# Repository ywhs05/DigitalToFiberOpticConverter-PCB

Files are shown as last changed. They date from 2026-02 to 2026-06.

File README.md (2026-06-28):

# DigitalToFiberOpticConverter-PCB

### Descripción
Proyecto del laboratorio LabCES de la Universidad de Costa Rica.

<!-- Este circuito tiene como objetivo recibir las señales digitales enviadas por medio de un microcontrolador para luego convertirlas en fibra óptica para que pueda ser leída por los puentes H [PEH2015 de Imperix](DaFO-PCB/Datasheets/PEH2015-PuenteH.pdf) en su entrada de fibra óptica. -->

Este circuito tiene como objetivo recibir una señal PWM digital enviada por medio de un microcontrolador, para luego ser convertida en una señal de fibra óptica para poder ser leída por los puentes H [PEH2015 de Imperix](DaFO-PCB/Datasheets/PEH2015-PuenteH.pdf) en su entrada de fibra óptica.

<!--![PCB](DAFO-PCB/Imagenes/PCB.png)-->

Ahora bien, la placa cuenta con la posiblidad de agregar o no, tiempo muerto a la señal PWM por seguridad de los transistores del puente H. Dicho tiempo muerto es ajustable mediante un trimmer. Por otra parte, es posible negar la señal PWM o no.

En adición, se puede adicionar una placa igual por encima de otra para aprovechar la señal PWM recibida del microcontrolador y se cuentan 3 huecos para colocar los pilares de nylon para su soporte.

Finalmente, se muestran las vistas superior e inferior de la PCB.

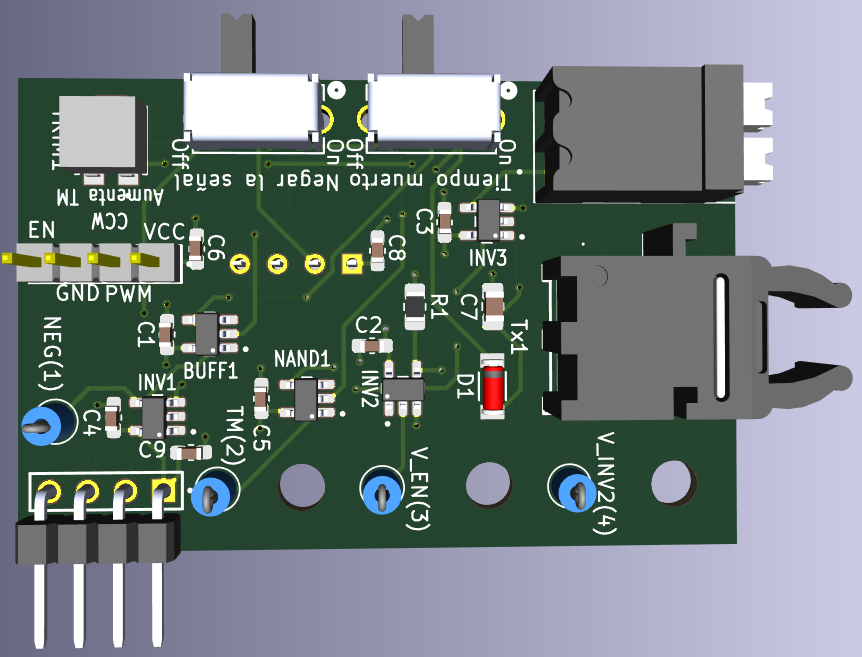
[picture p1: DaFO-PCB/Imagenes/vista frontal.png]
PCB_3D_sup


PCB_3D_inf

### Soporte
- y.huang@ucr.ac.cr
- mauricio.espinoza_bola@ucr.ac.cr

### Estado del proyecto

Se encuentra en proceso de pruebas experimentales.

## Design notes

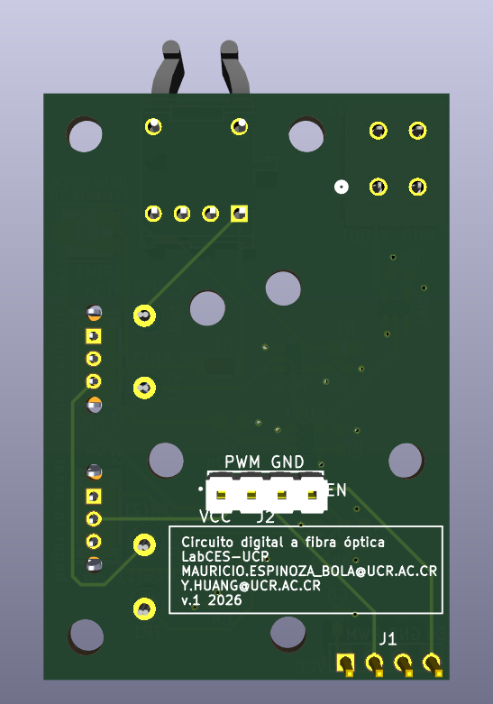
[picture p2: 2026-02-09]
DaFO-PCB/Imagenes/PCB_3D_inf.png

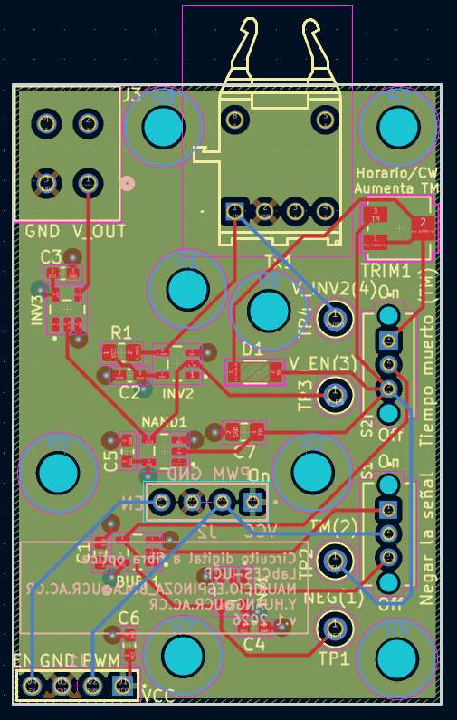
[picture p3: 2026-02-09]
DaFO-PCB/Imagenes/PCB.png

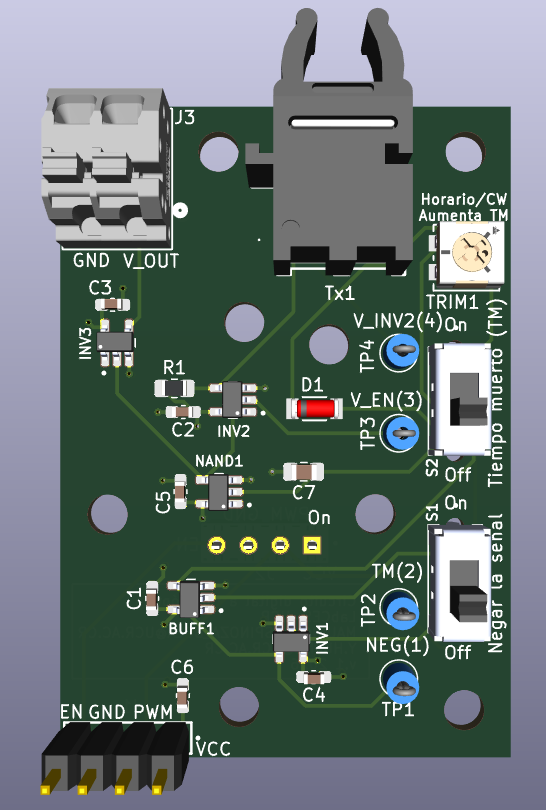
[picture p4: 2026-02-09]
DaFO-PCB/Imagenes/PCB_3D_sup.png

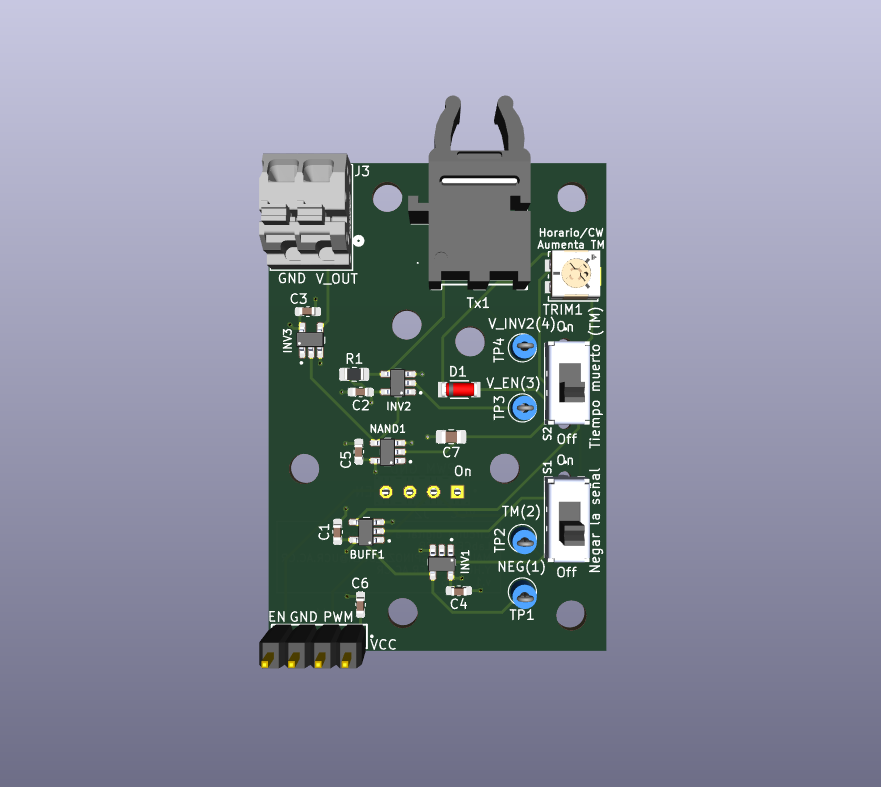
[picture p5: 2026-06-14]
DaFO-PCB/Imagenes/PCB_3D.png

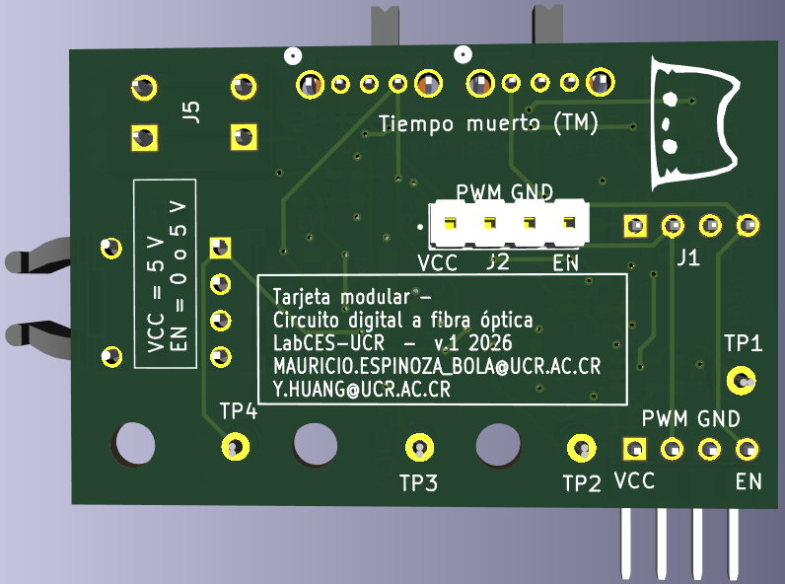
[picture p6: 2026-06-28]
DaFO-PCB/Imagenes/vista trasera.png

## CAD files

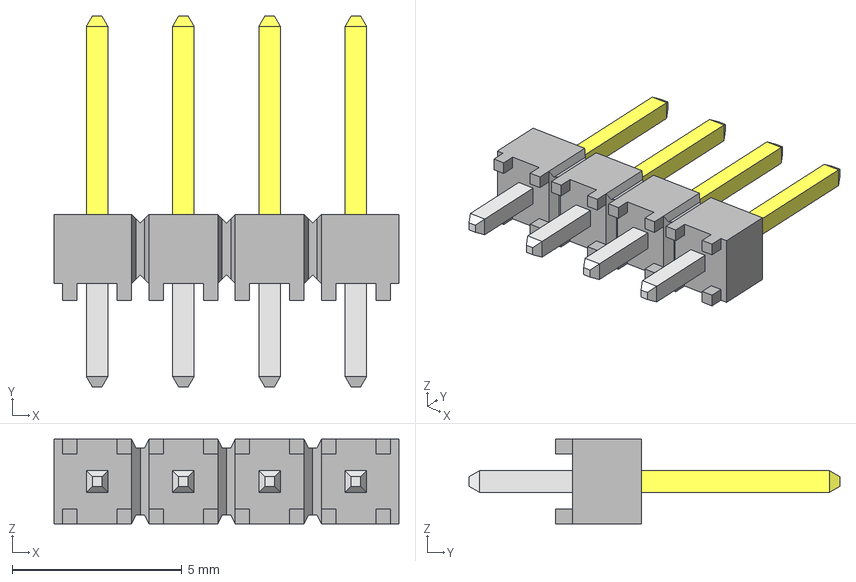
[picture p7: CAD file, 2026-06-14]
DaFO-PCB/DaFO/3D models/HTSW-104-07-F-S_3D.stp
10.2 x 10.9 x 2.49 mm
HTSW-104-07-F-S_body
T-1S6-07-HTSW-1--07-4--F-S
T-1S6-07-HTSW-1--07-4--F-S2

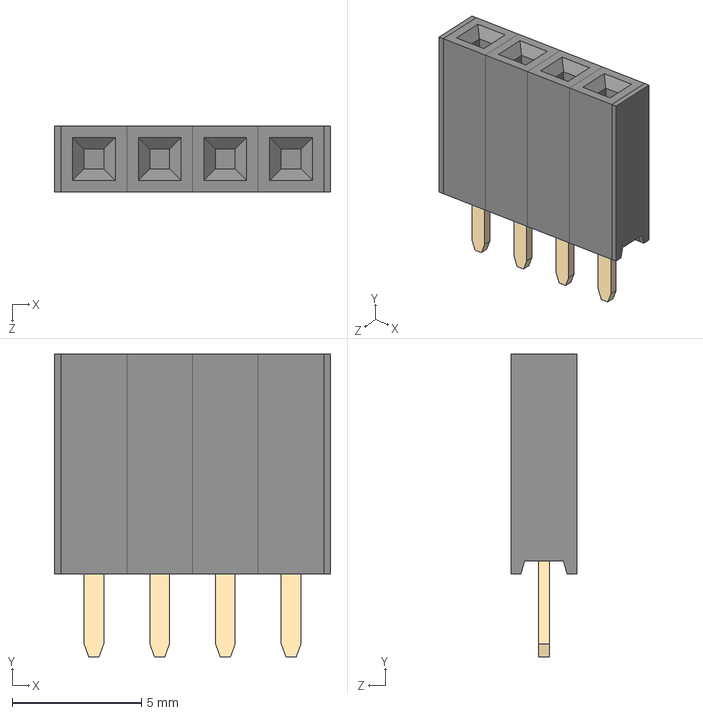
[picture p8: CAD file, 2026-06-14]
DaFO-PCB/DaFO/3D models/CONN_PPPC041LFBN-RC.STEP
10.7 x 11.7 x 2.54 mm
PPPC021LFBN-RC_C04
Pin - Gold x 4

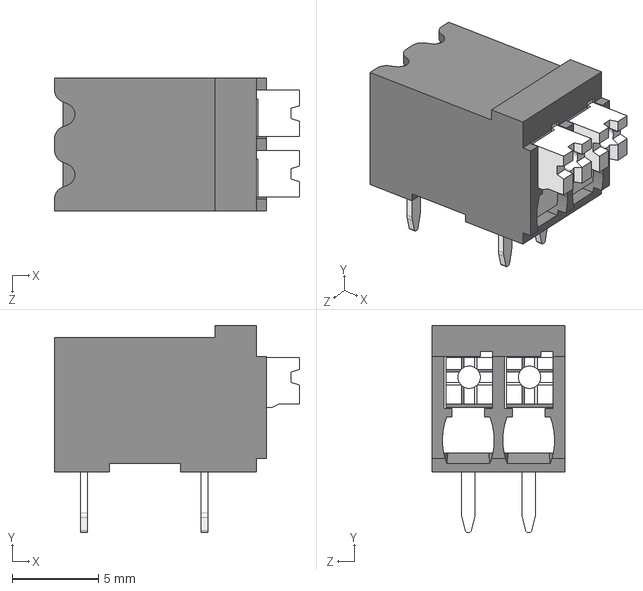
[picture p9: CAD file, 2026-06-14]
DaFO-PCB/DaFO/3D models/CON_TBLH10-350-02BK.step
14.2 x 12.0 x 7.70 mm

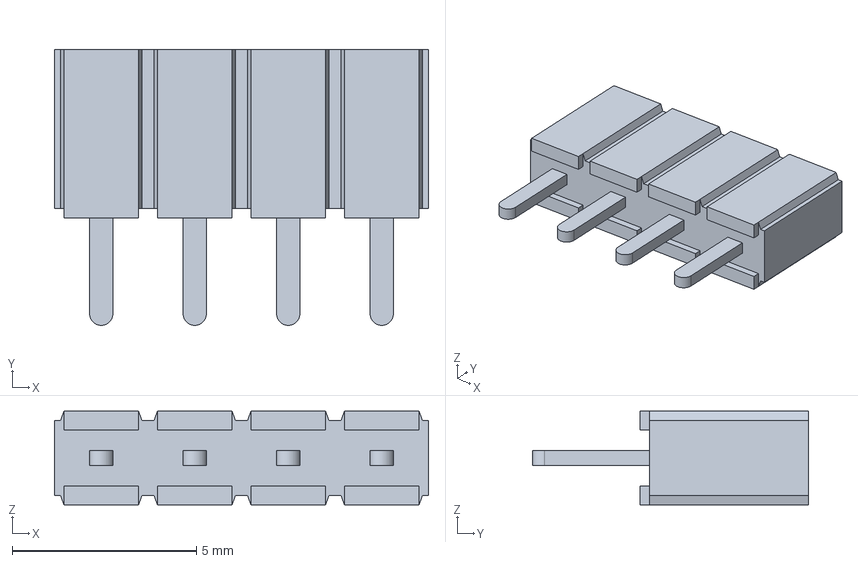
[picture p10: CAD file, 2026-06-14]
DaFO-PCB/DaFO/3D models/CONN_slw-104-01-f-s.stp
10.2 x 7.49 x 2.54 mm

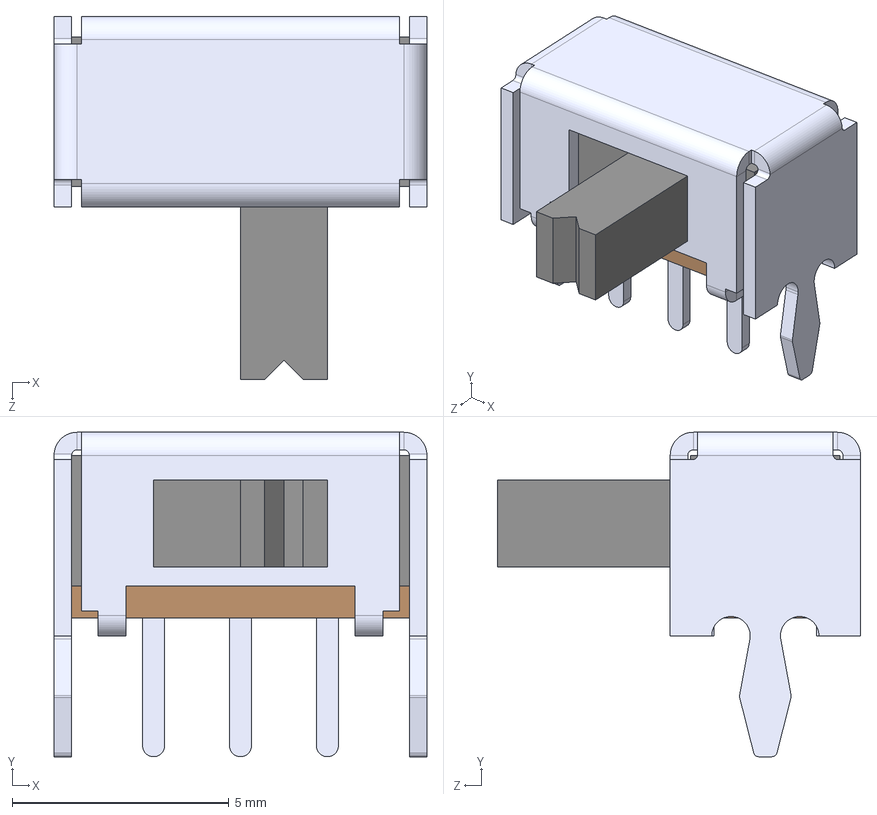
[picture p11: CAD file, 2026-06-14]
DaFO-PCB/DaFO/3D models/SWITCH_OS102011MA1QN1.STEP
8.61 x 7.49 x 8.38 mm

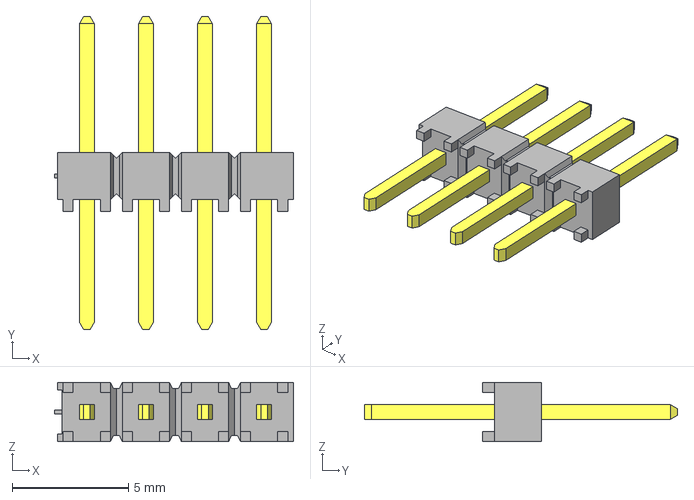
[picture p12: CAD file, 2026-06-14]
DaFO-PCB/DaFO/3D models/TSW-104-08-S-S.stp
10.3 x 13.5 x 2.54 mm
TSW-104-08-S-S_body
T-1S6-08-TSW-1-08-4-S

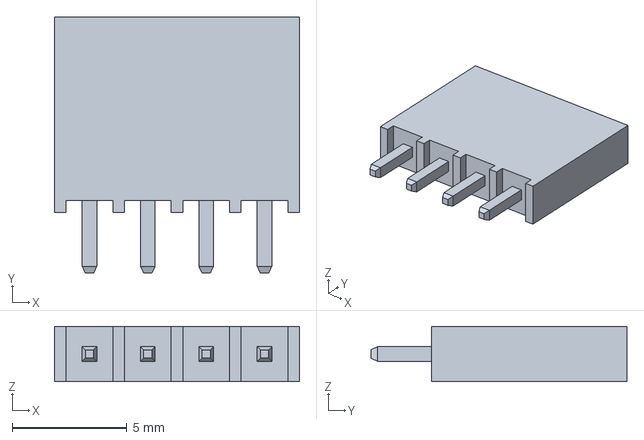
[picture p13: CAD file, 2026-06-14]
DaFO-PCB/DaFO/3D models/CONN_ssq-104-01-t-s.stp
10.7 x 11.2 x 2.41 mm

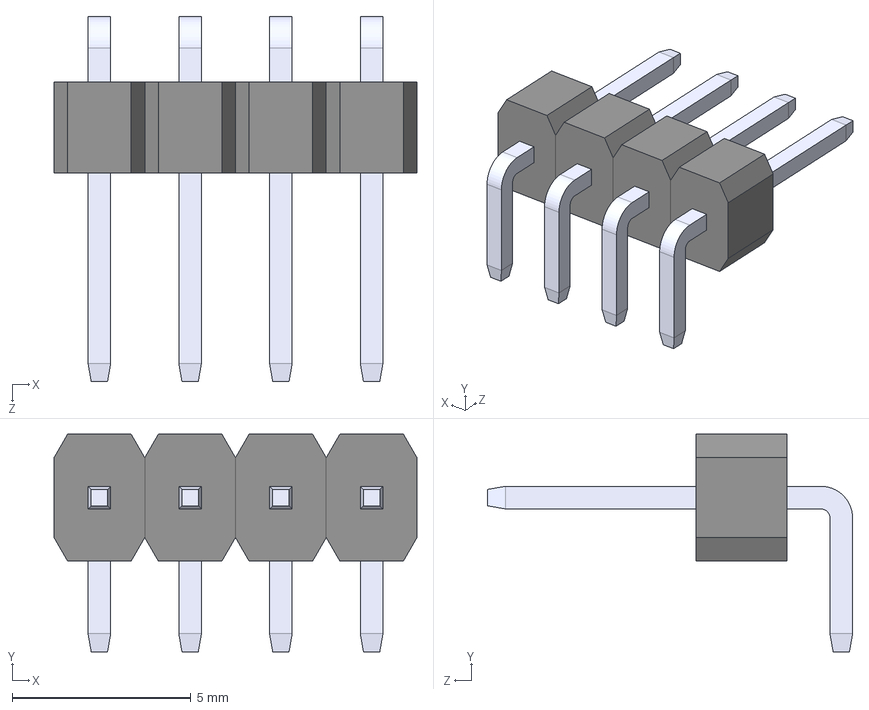
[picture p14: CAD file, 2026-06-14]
DaFO-PCB/DaFO/3D models/PEC04SBAN.STEP
10.2 x 6.10 x 10.2 mm
PBC04SBAN_GC04
Pin - Tin_BA x 4

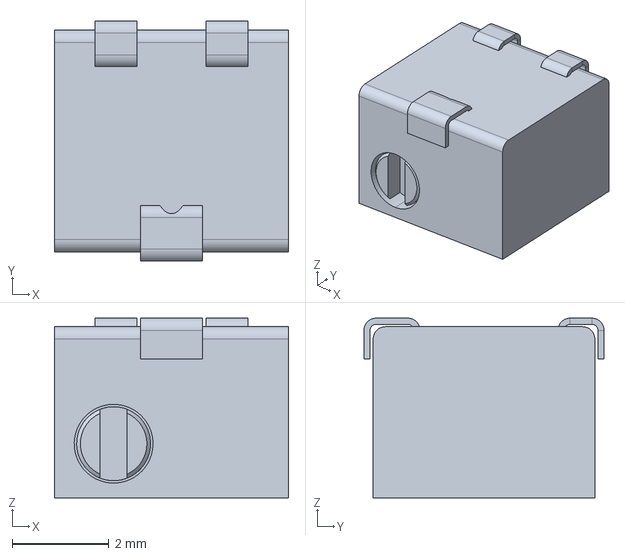
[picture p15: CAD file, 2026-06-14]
DaFO-PCB/DaFO/3D models/TRIM_3214J.stp
4.83 x 4.95 x 3.71 mm

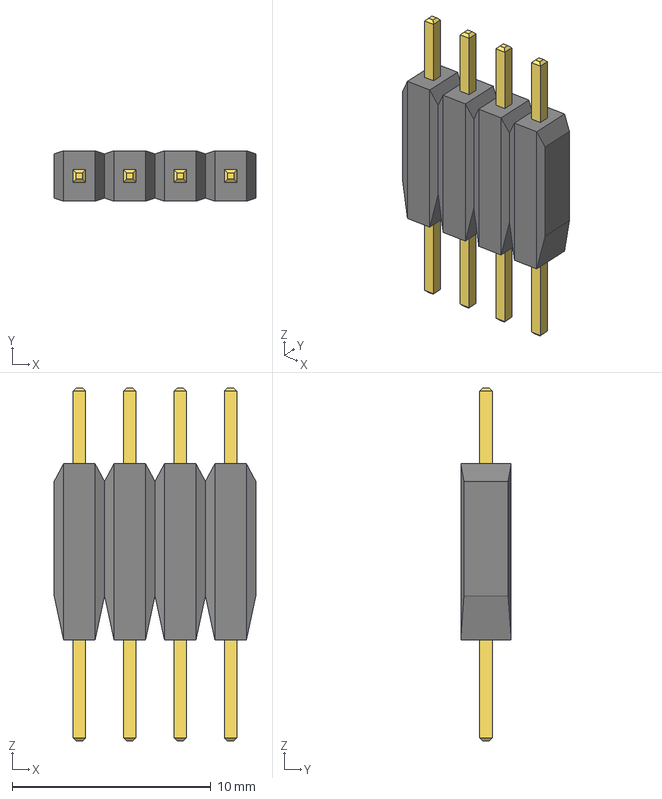
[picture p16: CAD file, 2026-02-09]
DaFO-PCB/DaFO/3D models/HTSW_104_07_F_S.step
10.2 x 2.54 x 17.8 mm

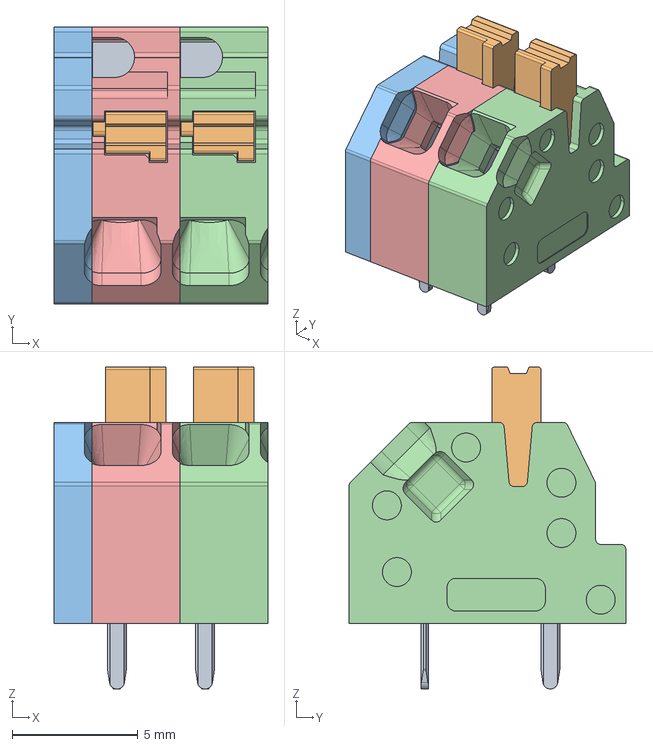
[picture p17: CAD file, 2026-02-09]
DaFO-PCB/DaFO/3D models/CON_1862042.stp
8.50 x 11.0 x 12.8 mm

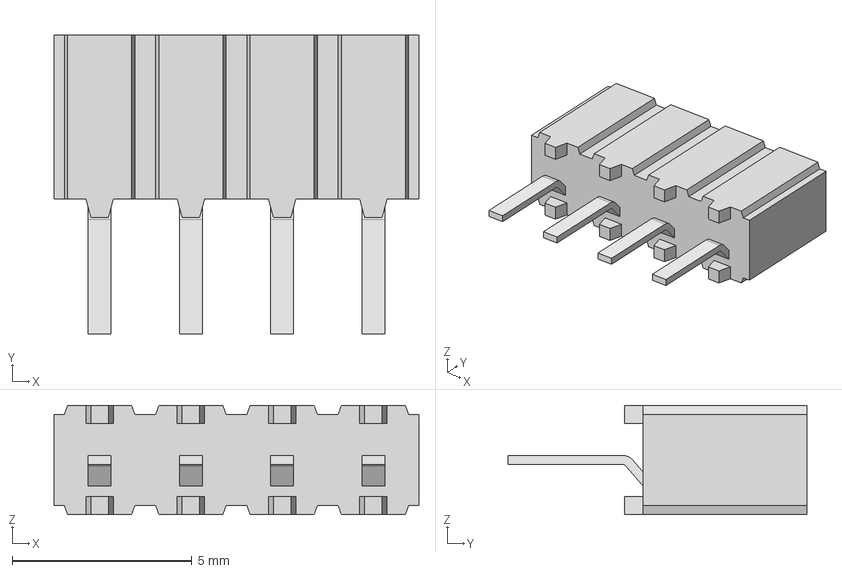
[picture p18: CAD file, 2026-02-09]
DaFO-PCB/DaFO/3D models/CES-104-01-L-S.stp
10.2 x 8.33 x 3.05 mm
CES-104-01-S_socket
010401LS
010401LS2

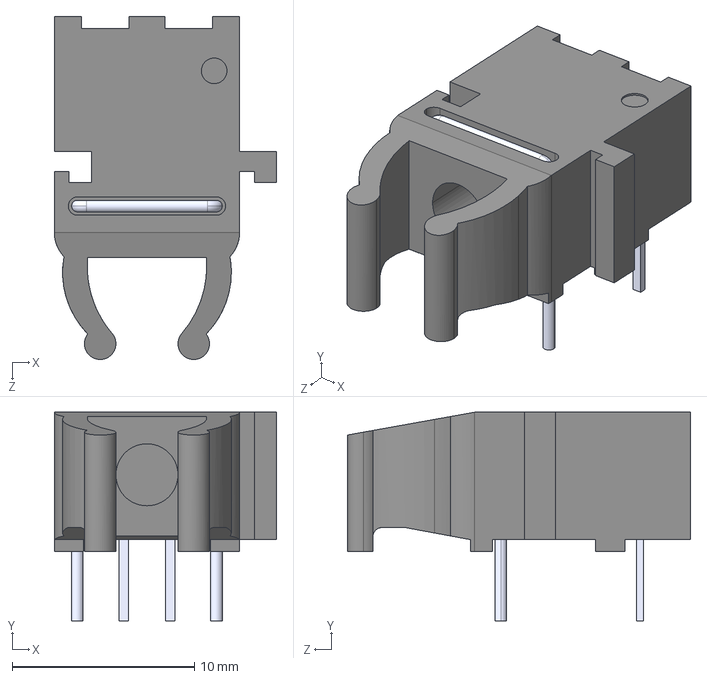
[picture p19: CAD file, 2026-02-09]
DaFO-PCB/DaFO/3D models/HFBR-2521Z.stp
12.2 x 11.4 x 18.8 mm

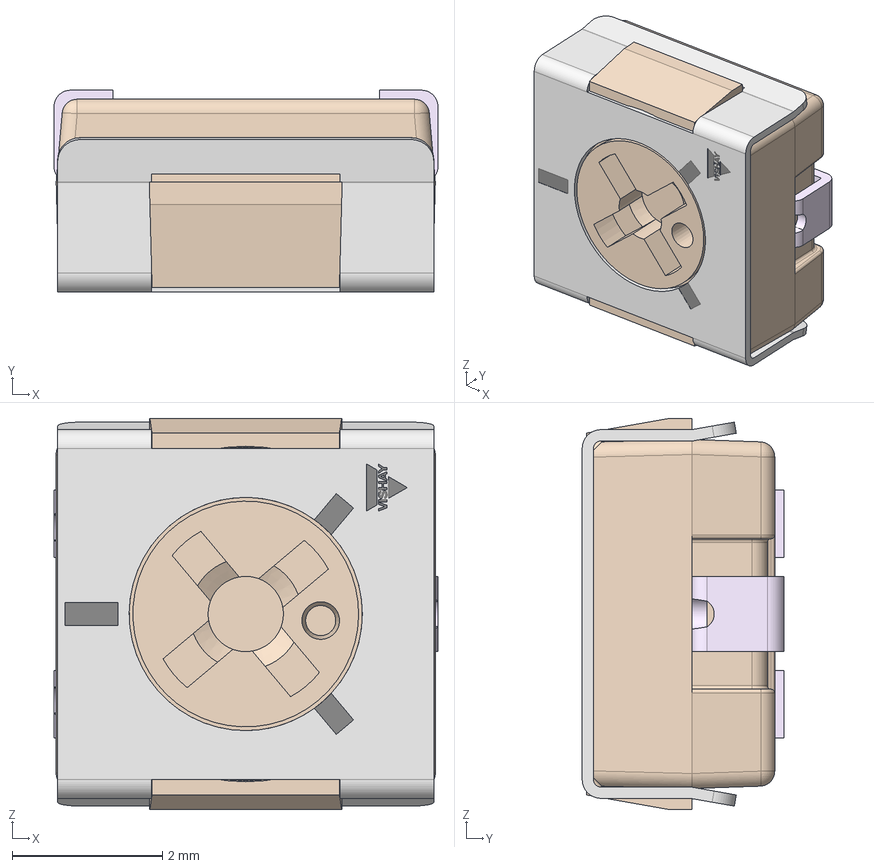
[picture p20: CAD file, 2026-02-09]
DaFO-PCB/DaFO/3D models/TS53YJxxx.stp
5.10 x 2.68 x 5.20 mm
3936100-contraint
3935201-J

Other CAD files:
DaFO-PCB/DaFO/3D models/CONN_ssw-104-01-t-s.stp
DaFO-PCB/DaFO/3D models/SN74AHC1G14DBVR.step
DaFO-PCB/DaFO/3D models/BAS85_GS08.stp
DaFO-PCB/DaFO/3D models/SN74AHC1G00DBVR.step
DaFO-PCB/DaFO/3D models/282858-2.step
DaFO-PCB/DaFO/3D models/CAP_X7R_0603_AVX.step
DaFO-PCB/DaFO/3D models/CON_PC_1935776.step
DaFO-PCB/DaFO/3D models/HFBR-1521Z.stp
DaFO-PCB/DaFO/3D models/OS102011MS2QN1.step
DaFO-PCB/DaFO/3D models/SN74LVC1G06DBVR.step
DaFO-PCB/DaFO/3D models/SN74LVC1G17DBVR.step

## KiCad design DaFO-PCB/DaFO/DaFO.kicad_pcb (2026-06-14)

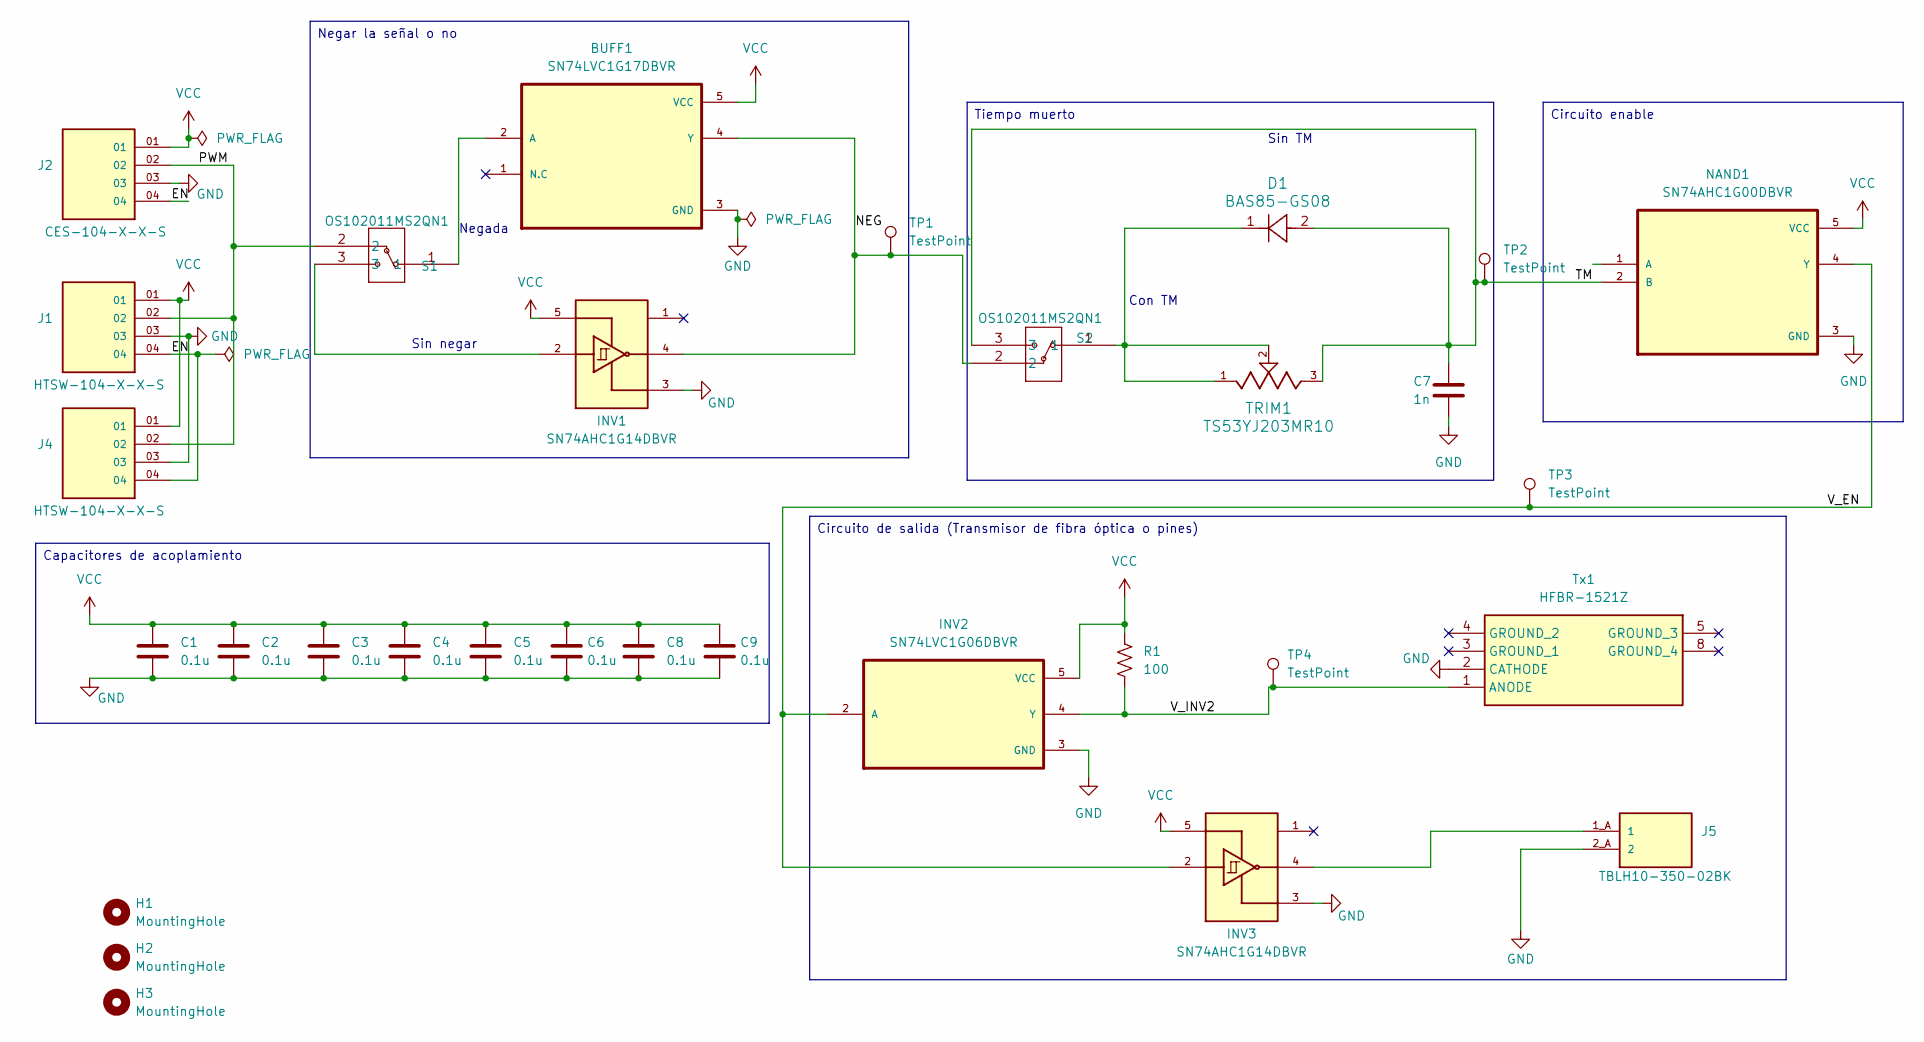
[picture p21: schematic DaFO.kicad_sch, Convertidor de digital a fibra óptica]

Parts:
BUFF1: SN74LVC1G17DBVR; SOT95P280X145-5N
C1, C2, C3, C4, C5, C6, C8, C9: 0.1u; C_0603_1608Metric_Pad1.08x0.95mm_HandSolder
C7: 1n; C_0805_2012Metric_Pad1.18x1.45mm_HandSolder
D1: BAS85-GS08; MELF_BAS_8X_VIS
H1, H2, H3: MountingHole; MountingHole_3.2mm_M3
INV1, INV3: SN74AHC1G14DBVR; PARTREV Q
INV2: SN74LVC1G06DBVR
J1, J4: HTSW-104-X-X-S; SAMTEC_HTSW-104-X-X-S; PARTREV B
J2: CES-104-X-X-S; SAMTEC_CES-104-X-X-S; PARTREV A
J5: TBLH10-350-02BK; CUI_TBLH10-350-02BK
NAND1: SN74AHC1G00DBVR; SOT95P280X145-5N
R1: 100; R_0805_2012Metric_Pad1.20x1.40mm_HandSolder
S1, S2: OS102011MS2QN1; OS102011MA1QN1_CNK
TP1, TP2, TP3, TP4: TestPoint; TestPoint_Loop_D1.80mm_Drill1.0mm_Beaded
TRIM1: TS53YJ203MR10; TRIM_3214J-1-203E; PARTREV 06/24
Tx1: HFBR-1521Z; HFBR1521Z; Mouser Part Number 630-HFBR-1521Z

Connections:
/EN: J1.04, J2.04, J4.04
/NEG: BUFF1.4 (Y), INV1.4, S2.2, TP1.1
/PWM: J1.02, J2.02, J4.02, S1.2
/TM: C7.1, D1.2, NAND1.2 (B), S2.3, TP2.1, TRIM1.3
/V_EN: INV2.2 (A), INV3.2, NAND1.4 (Y), TP3.1
/V_INV2: INV2.4 (Y), R1.2, TP4.1, Tx1.1 (ANODE)
GND: BUFF1.3 (GND), C1.2, C2.2, C3.2, C4.2, C5.2, C6.2, C7.2, C8.2, C9.2, INV1.3, INV2.3 (GND), INV3.3, J1.03, J2.03, J4.03, J5.2_A (2), NAND1.3 (GND), Tx1.2 (CATHODE)
unnamed: BUFF1.2 (A), S1.1
unnamed: D1.1, S2.1, TRIM1.1, TRIM1.2
unnamed: INV1.2, S1.3
unnamed: INV3.4, J5.1_A (1)
VCC: BUFF1.5 (VCC), C1.1, C2.1, C3.1, C4.1, C5.1, C6.1, C8.1, C9.1, INV1.5, INV2.5 (VCC), INV3.5, J1.01, J2.01, J4.01, NAND1.5 (VCC), R1.1

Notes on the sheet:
Sin TM
Con TM
Sin negar
Negada
Negar la señal o no
Circuito de salida (Transmisor de fibra óptica o pines)
Tiempo muerto
Capacitores de acoplamiento
Circuito enable

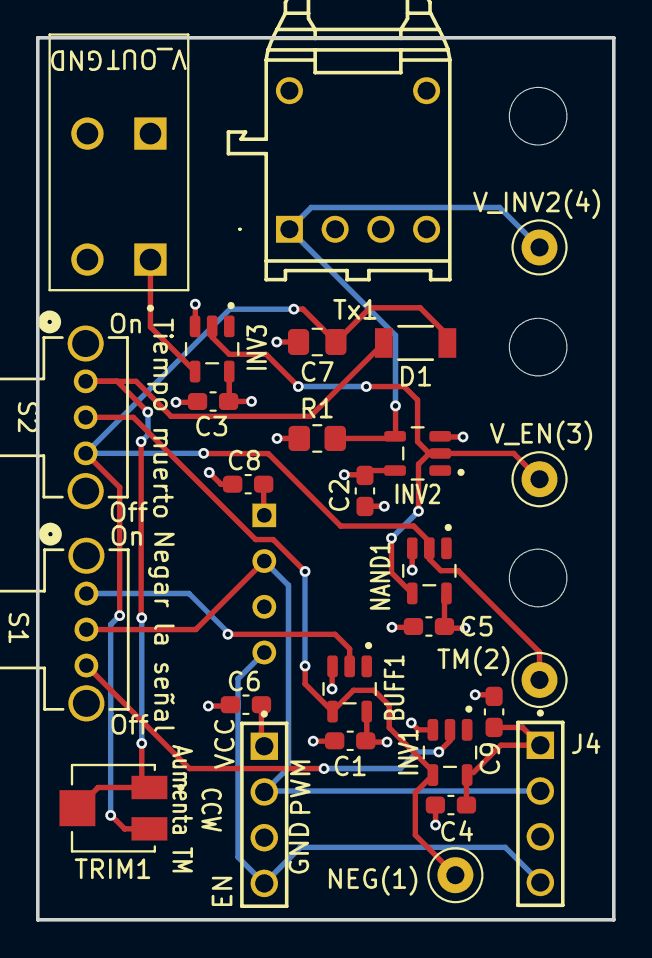
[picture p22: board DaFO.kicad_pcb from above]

Board: 4 copper layers, 32.0 x 49.0 mm, 31 parts (1 on the bottom side), 12 nets.

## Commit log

2026-01-11 Creación del archivo en KiCad
    [DaFO.kicad_pcb, DaFO.kicad_sch]
2026-01-11 Añadir archivo README y hojas de datos de interés de componentes a utilizar en la pcb.
2026-02-09 Elaboración y diseño del circuito convertidor de digital a fibra óptica modular.
    [282858-2.step, BAS85_GS08.stp, CAP_X7R_0603_AVX.step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]
2026-02-09 Actualización del README e información en el esquemático de la placa.
    [DaFO.kicad_sch]
2026-06-14 Cambios para reducir tamaño y a componentes laterales. Creación de archivos de fabricación.
    Se realizaron cambios a la PCB para reducir su tamaño, se cambiaron ciertos componentes y se tienen los archivos de fabricación de la placa.
    [CONN_PPPC041LFBN-RC.STEP, CONN_slw-104-01-f-s.stp, CONN_ssq-104-01-t-s.stp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]
2026-06-28 Actualización de archivo README.md
    Adición de imágenes y cambio de estado del proyecto.
    [DaFO.kicad_sch]

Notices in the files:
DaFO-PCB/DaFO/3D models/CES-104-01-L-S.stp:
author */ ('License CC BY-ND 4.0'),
